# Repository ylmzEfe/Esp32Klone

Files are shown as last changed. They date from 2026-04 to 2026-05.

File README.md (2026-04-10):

# Esp32Klone
A custom ESP32-based PCB designed from scratch in KiCad.  
*This is my first ESP32 and KiCad project — built to learn PCB design fundamentals.*
## Features
- ESP32-WROOM-32E module
- USB-C connectivity
- CH340G USB-to-UART bridge
- AMS1117-3.3 voltage regulator
- Automatic bootloader circuit
## Status
Completed.

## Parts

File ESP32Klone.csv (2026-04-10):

Reference | Qty | Value | DNP | Exclude from BOM | Exclude from Board | Footprint | Datasheet
C1,C2 | 2 | 22pF |  |  |  | PCM_4ms_Capacitor:C_0603 | ~
C3,C4,C5,C7 | 4 | 100nF |  |  |  | PCM_4ms_Capacitor:C_0603 | ~
C6 | 1 | 10uF |  |  |  | PCM_4ms_Capacitor:C_0805 | ~
C8 | 1 | 100uF |  |  |  | Capacitor_SMD:CP_Elec_6.3x5.4 | ~
D1 | 1 | LED |  |  |  | LED_SMD:LED_0603_1608Metric | ~
J1 | 1 | USB_C_Receptacle_USB2.0_14P |  |  |  | Connector_USB:USB_C_Receptacle_HRO_TYPE-C-31-M-12 | https://www.usb.org/sites/default/files/documents/usb_type-c.zip
J2,J3 | 2 | Conn_01x14_Socket |  |  |  | Connector_PinHeader_2.54mm:PinHeader_1x14_P2.54mm_Vertical | ~
R1,R2 | 2 | 5.1k |  |  |  | PCM_4ms_Resistor:R_0603 | ~
R3,R4,R5 | 3 | 10k |  |  |  | PCM_4ms_Resistor:R_0603 | ~
R6 | 1 | 1k |  |  |  | PCM_4ms_Resistor:R_0603 | ~
R7 | 1 | 20k |  |  |  | PCM_4ms_Resistor:R_0603 | ~
U1 | 1 | CH340G |  |  |  | Package_SO:SOIC-16_3.9x9.9mm_P1.27mm | http://www.datasheet5.com/pdf-local-2195953
U2 | 1 | AMS1117-3.3 |  |  |  | Package_TO_SOT_SMD:SOT-223-3_TabPin2 | http://www.advanced-monolithic.com/pdf/ds1117.pdf
U3 | 1 | ESP32-WROOM-32E |  |  |  | RF_Module:ESP32-WROOM-32D | https://www.espressif.com/sites/default/files/documentation/esp32-wroom-32e_esp32-wroom-32ue_datasheet_en.pdf
X1 | 1 | 12MHz |  |  |  | Crystal:Crystal_SMD_HC49-SD | ~

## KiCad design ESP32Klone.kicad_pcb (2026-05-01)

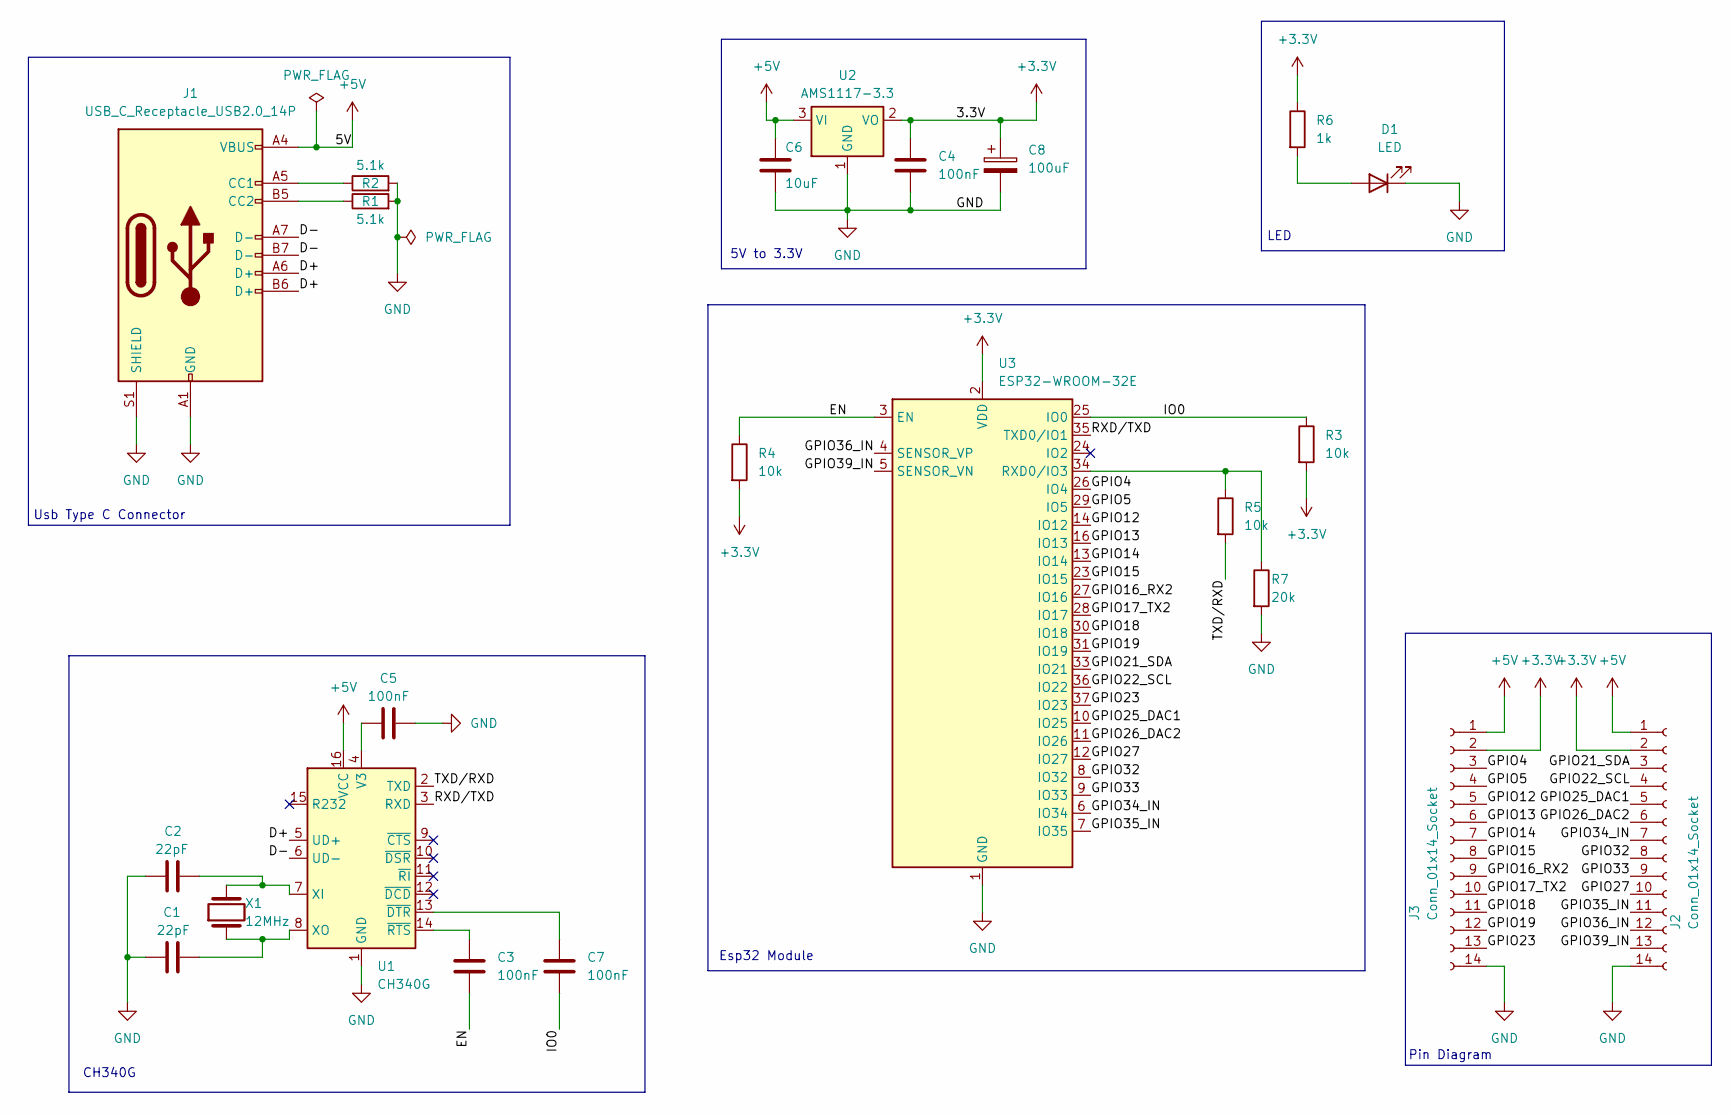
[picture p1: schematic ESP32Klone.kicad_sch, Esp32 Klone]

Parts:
C1, C2: 22pF; C_0603
C3, C4, C5, C7: 100nF; C_0603
C6: 10uF; C_0805
C8: 100uF; CP_Elec_6.3x5.4
D1: LED; LED_0603_1608Metric
J1: USB_C_Receptacle_USB2.0_14P; USB_C_Receptacle_HRO_TYPE-C-31-M-12
J2, J3: Conn_01x14_Socket; PinHeader_1x14_P2.54mm_Vertical
R1, R2: 5.1k; R_0603
R3, R4, R5: 10k; R_0603
R6: 1k; R_0603
R7: 20k; R_0603
U1: CH340G; SOIC-16_3.9x9.9mm_P1.27mm
U2: AMS1117-3.3; SOT-223-3_TabPin2
U3: ESP32-WROOM-32E; ESP32-WROOM-32D
X1: 12MHz; Crystal_SMD_HC49-SD

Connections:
+3.3V: C4.1, C8.1, J2.2, J3.2, R3.2, R4.2, R6.1, U2.2 (VO), U3.2 (VDD)
+5V: C6.1, J1.A4 (VBUS), J1.A9 (VBUS), J1.B4 (VBUS), J1.B9 (VBUS), J2.1, J3.1, U1.16 (VCC), U2.3 (VI)
/D+: J1.A6 (D+), J1.B6 (D+), U1.5 (UD+)
/D-: J1.A7 (D-), J1.B7 (D-), U1.6 (UD-)
/EN: C3.2, R4.1, U3.3 (EN)
/GPIO4: J3.3, U3.26 (IO4)
/GPIO5: J3.4, U3.29 (IO5)
/GPIO12: J3.5, U3.14 (IO12)
/GPIO13: J3.6, U3.16 (IO13)
/GPIO14: J3.7, U3.13 (IO14)
/GPIO15: J3.8, U3.23 (IO15)
/GPIO16_RX2: J3.9, U3.27 (IO16)
/GPIO17_TX2: J3.10, U3.28 (IO17)
/GPIO18: J3.11, U3.30 (IO18)
/GPIO19: J3.12, U3.31 (IO19)
/GPIO21_SDA: J2.3, U3.33 (IO21)
/GPIO22_SCL: J2.4, U3.36 (IO22)
/GPIO23: J3.13, U3.37 (IO23)
/GPIO25_DAC1: J2.5, U3.10 (IO25)
/GPIO26_DAC2: J2.6, U3.11 (IO26)
/GPIO27: J2.10, U3.12 (IO27)
/GPIO32: J2.8, U3.8 (IO32)
/GPIO33: J2.9, U3.9 (IO33)
/GPIO34_IN: J2.7, U3.6 (IO34)
/GPIO35_IN: J2.11, U3.7 (IO35)
/GPIO36_IN: J2.12, U3.4 (SENSOR_VP)
/GPIO39_IN: J2.13, U3.5 (SENSOR_VN)
/IO0: C7.2, R3.1, U3.25 (IO0)
/RXD/TXD: U1.3 (RXD), U3.35 (TXD0/IO1)
/TXD/RXD: R5.2, U1.2 (TXD)
GND: C1.1, C2.1, C4.2, C5.2, C6.2, C8.2, D1.1 (K), J1.A1 (GND), J1.A12 (GND), J1.B1 (GND), J1.B12 (GND), J1.S1 (SHIELD), J2.14, J3.14, R1.2, R2.2, R7.2, U1.1 (GND), U2.1 (GND), U3.1 (GND), U3.15 (GND), U3.38 (GND), U3.39 (GND)
unnamed: D1.2 (A), R6.2
unnamed: J1.A5 (CC1), R2.1
unnamed: J1.B5 (CC2), R1.1
unnamed: C5.1, U1.4 (V3)
unnamed: C2.2, U1.7 (XI), X1.2
unnamed: C1.2, U1.8 (XO), X1.1
unnamed: C7.1, U1.13 (~DTR)
unnamed: C3.1, U1.14 (~RTS)
unnamed: R5.1, R7.1, U3.34 (RXD0/IO3)

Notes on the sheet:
CH340G
Usb Type C Connector
Pin Diagram
5V to 3.3V
Esp32 Module
LED

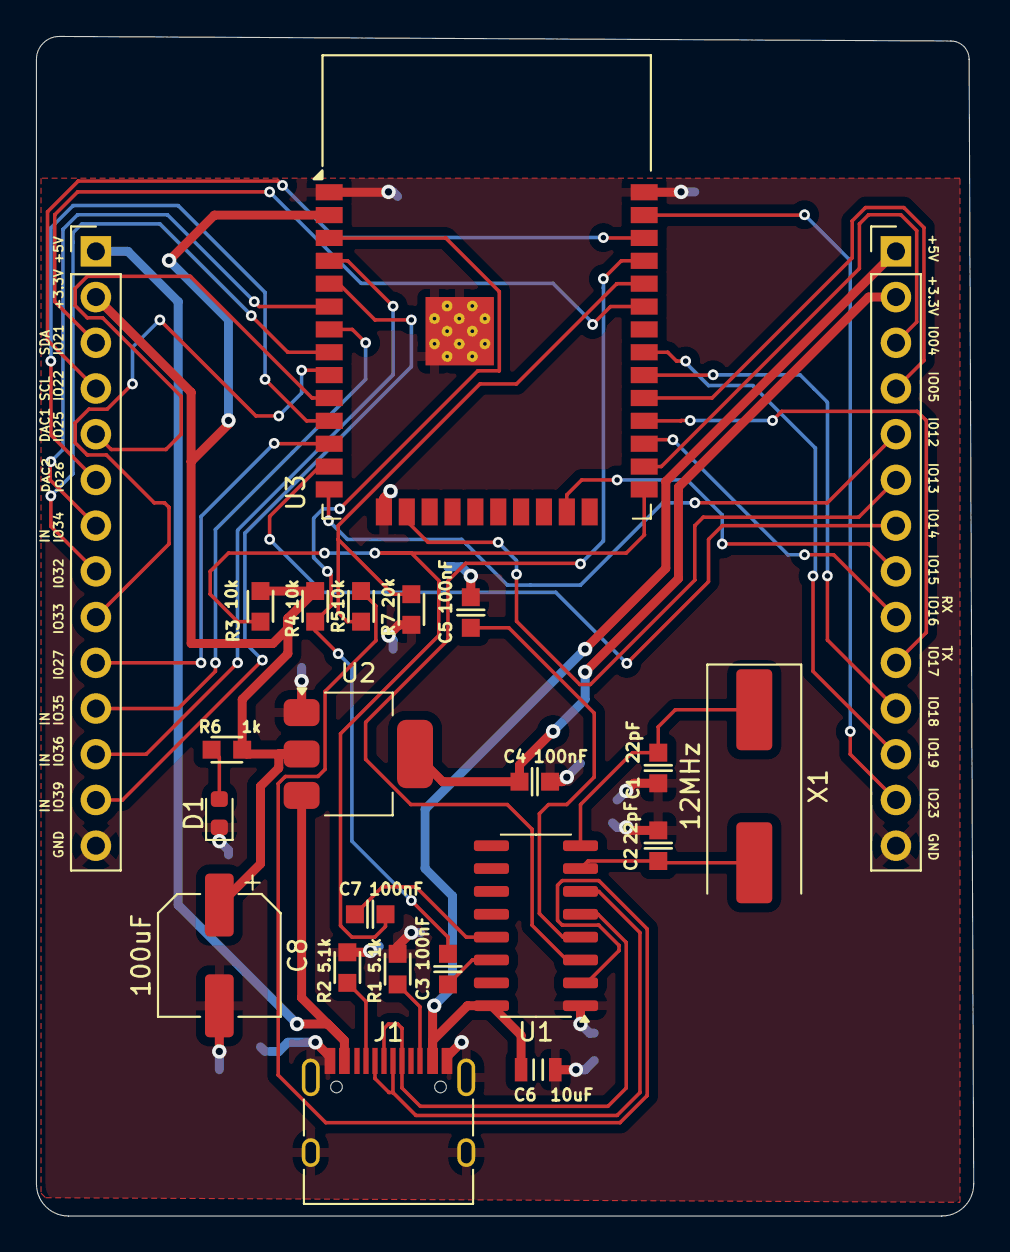
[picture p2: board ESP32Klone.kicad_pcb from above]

Board: 2 copper layers, 52.1 x 65.5 mm, 23 parts (0 on the bottom side), 40 nets.

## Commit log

2026-04-10 Esp32 ilk
    [ESP32Klone-B_Cu.gbr, ESP32Klone-B_Mask.gbr, ESP32Klone-B_Paste.gbr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]
2026-04-13 fix: correct UART Rx level shifter wiring (R5/R7)
    [ESP32Klone-B_Cu.gbr, ESP32Klone-B_Mask.gbr, ESP32Klone-B_Paste.gbr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]
2026-04-28 Added F.Cu copperfill
    [ESP32Klone.kicad_pcb]
2026-05-01 fix: silkscreen GPIO39 label corrected
    [ESP32Klone.kicad_pcb]
